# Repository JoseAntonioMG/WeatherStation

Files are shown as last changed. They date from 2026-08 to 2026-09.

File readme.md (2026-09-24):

# Project introduction

I created this project as a personal challenge to build a weather station, and also as a way to make use of an OpenThread mesh network using EspHome + HomeAssistant.

# Project function

1. Measure ambient temperature, humidity, and atmospheric pressure.

2. Measure the amount and intensity of rainfall.

3. Measure wind speed.

4. Measure wind direction.

# Hardware

I want to fabricate a PCB from the design I created in EasyEDA, which is shown in this program. The design includes the following elements:

1. An ESP32C6 microprocessor from espressif.
2. A lithium battery power system consisting of:
  - 3.7V single-cell lithium battery 18650
  - solar panel
  - Lithium battery protection and charging circuit with the components TP4056, DW0A1, and FS8205A
  - Voltage regulator with the TPS63802 circuit
3. A BME280 sensor for measuring temperature, humidity, and atmospheric pressure
4. A DS18B20 sensor for measuring external temperature via a probe
5. A battery monitor with readings on an ESP32C6 GPIO ADC and a voltage divider.
6. Hall effect sensors are used in the rain gauge and the anemometer. Each sensor connects to the ESP32C6 via the analog GPIO pins.
7. AS5600 is 12-bit magnetic position sensor for wind direction

# Software

The ESP32C6 uses Thread technology for data transmission, so I used the EspHome system in conjunction with the open-source HomeAssistant application and an OpenThread Border Router for communication with the internal network.

EspHome enables firmware updates over the Thread network itself, meaning that a device located in a hard-to-reach place can be updated automatically without physical access.

# Other manufacturing

I designed the different elements for measuring rain and wind on the OnShape platform:
- A rain gauge
- An anemometer
- An weathervane (wind direction)

I printed both elements with PETG filament on a 3D printer, and this is the result:

# Image gallery

## PCB:
This a PCB build from LCDPCB

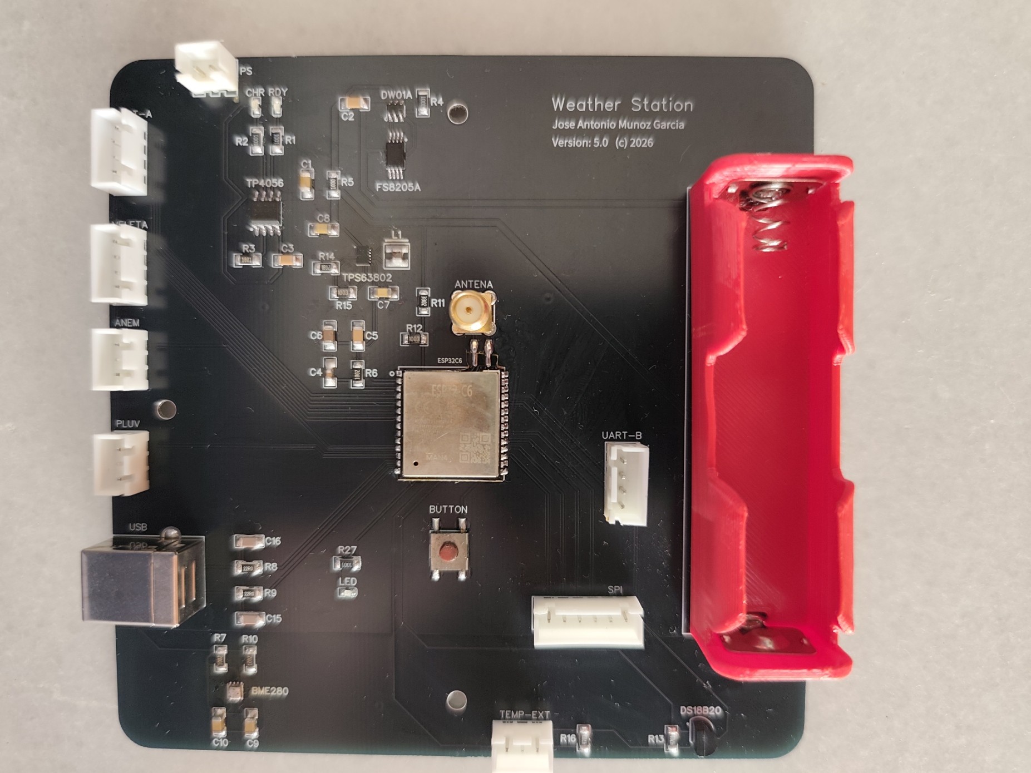
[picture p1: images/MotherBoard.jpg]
PCB


## Box outdoor and:
Airtight outdoor enclosure with grid for anchoring the PCB, battery and other electronic components.

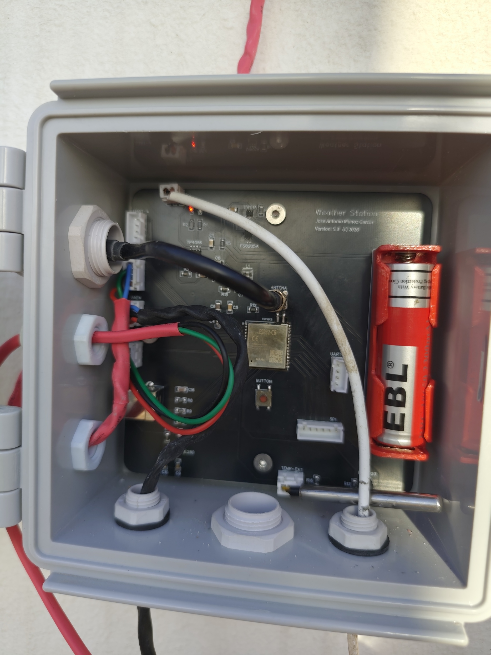
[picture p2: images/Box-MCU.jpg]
Outdoor Box


## BME280 Sensor:
The BME280 sensor from Bosch is a tiny device for soldering onto the PCB and records the internal temperature of the case where the MCU is located, as well as humidity and atmospheric pressure.

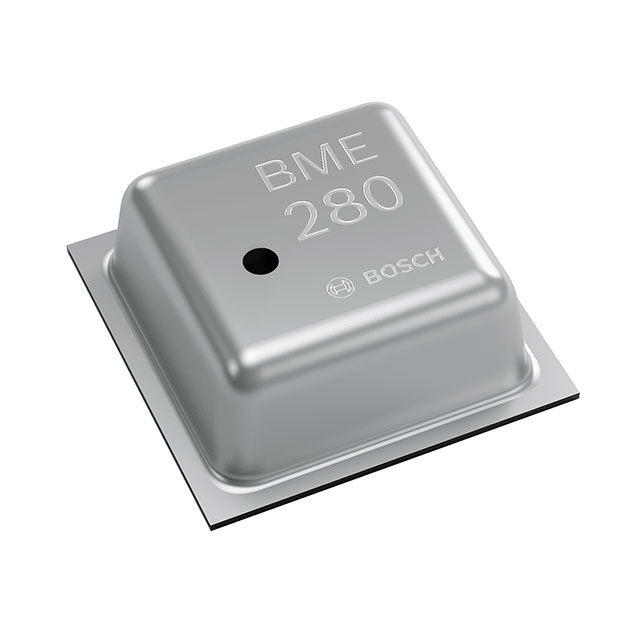
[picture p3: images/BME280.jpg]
BME280


## DS18B20 Sensor:
The DS18B20 is an outdoor temperature sensor; its metal sheath is protected against moisture and dust, and it can measure ambient temperature.

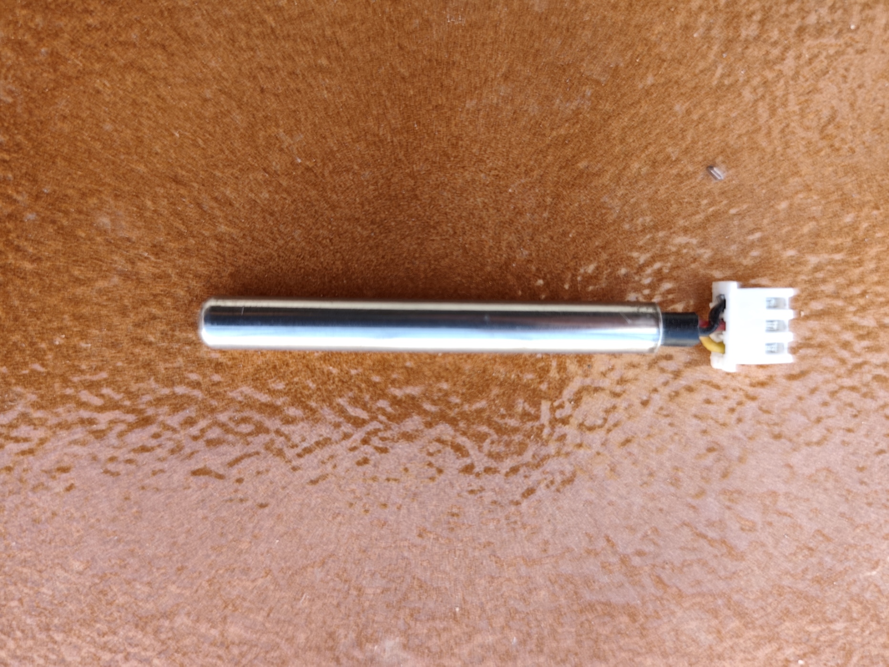
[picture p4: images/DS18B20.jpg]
DS18B20


## Rain Gauge:
Rain gauge seen from the outside, you can see the upper area (funnel) where there is a hole that allows water to enter and lead to the tipping bucket.

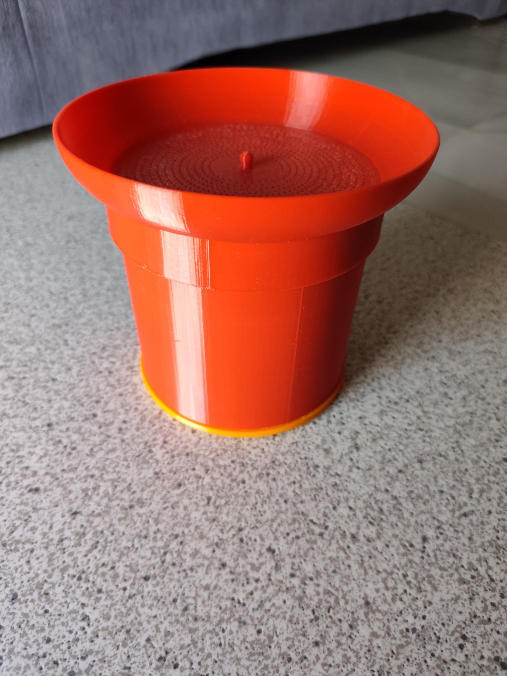
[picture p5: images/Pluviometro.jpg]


Interior rain gauge: the tipping bucket where the water falls can be seen, and in the front section, the Hall sensor that detects each revolution of the bucket. The neodymium magnet can be seen on the top of the tilting tank (a small metal piece). Using a mathematical formula, the amount of rainfall and intensity can be calculated for each revolution of the bucket, depending on the number of revolutions per minute.

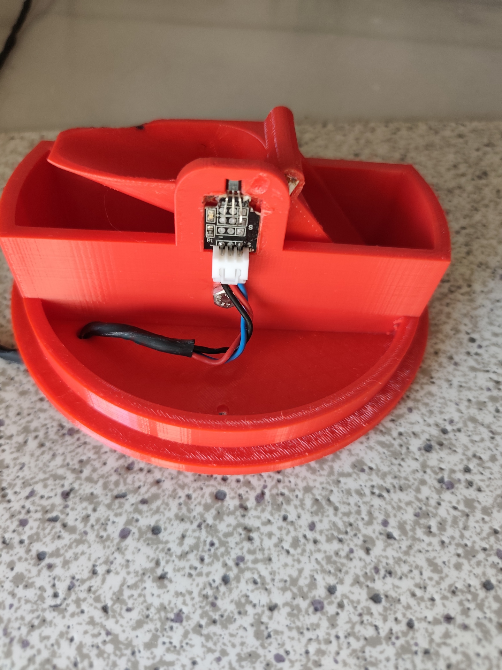
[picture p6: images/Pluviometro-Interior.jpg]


## Anemometer:
This device measures wind speed using a Hall effect sensor connected to its shaft and a neodymium magnet embedded in the rotating housing. Each pulse from the Hall sensor corresponds to one rotation of the device, and wind speed can be calculated using a mathematical formula.

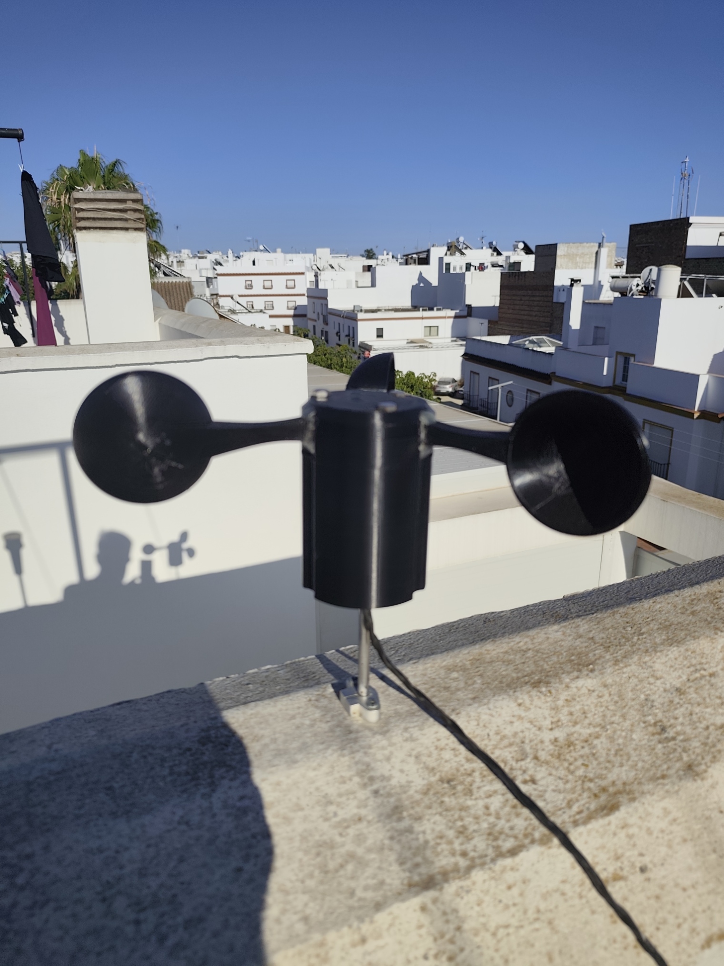
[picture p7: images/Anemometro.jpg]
Anenometer


## Weathervane:
Using an AS5600 sensor and a diametrically magnetized magnet. The AS5600 sensor remains fixed on a shaft; a dome containing the magnet at its base, approximately 2-3 mm from the sensor, rotates on this shaft. As the magnet rotates, the sensor can calculate its exact position in degrees and determine the wind direction.

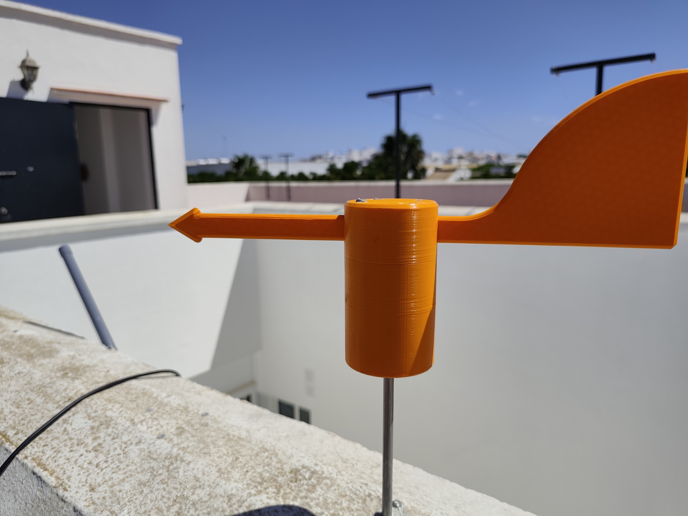
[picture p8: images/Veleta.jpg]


## Solar panel:
Allows the lithium battery to be recharged during daylight hours, and in this way the battery can power the MCU and sensors for many years.

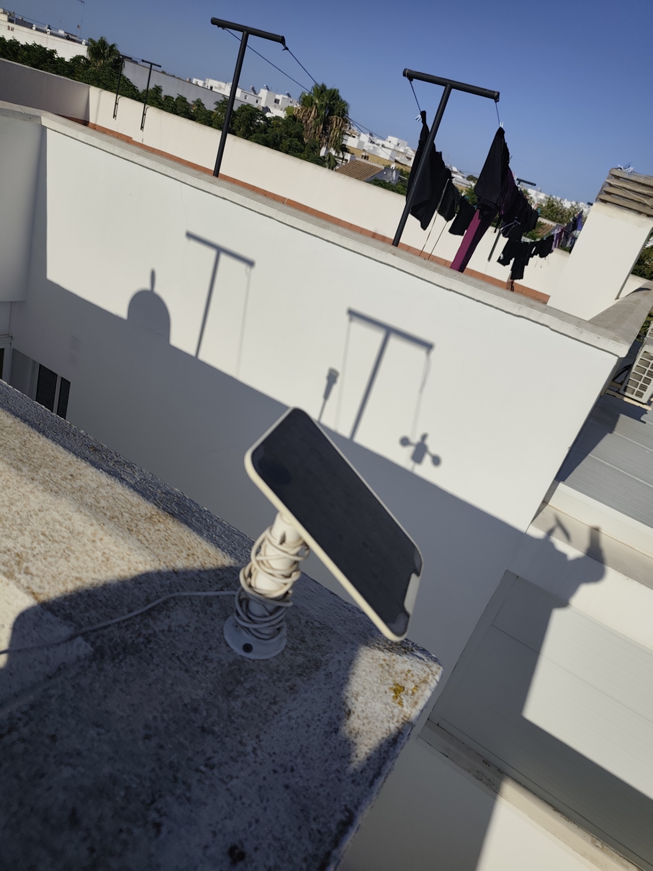
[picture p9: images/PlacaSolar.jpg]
Solar Panel


# OnShape Desing:

The rain gauge, anemometer and the weathervane were designed using the OnShape platform, and once designed they were printed on a 3D printer with PETG material.

General Rain Gauge Design:
https://cad.onshape.com/documents/2dcf995cedd97f664920bde0/w/8a44d4fc85dcee91b81b1610/e/77a74460ef746bb4184f5de4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

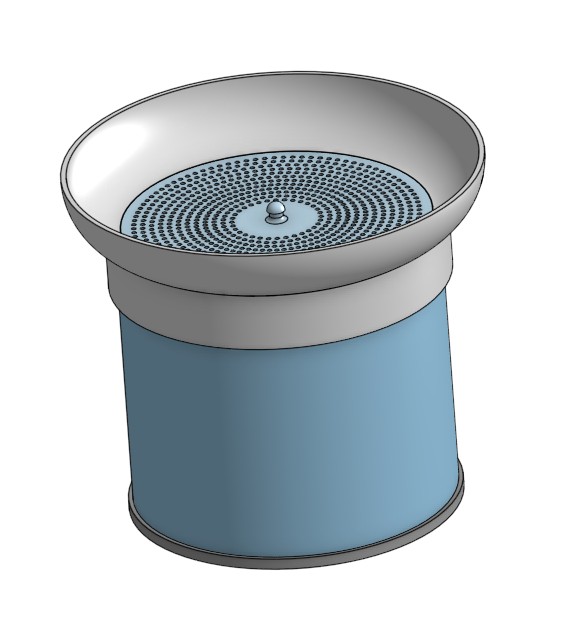
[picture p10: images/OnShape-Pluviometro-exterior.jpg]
Rain Gauge


Design of the interior rain gauge (tilting beam):

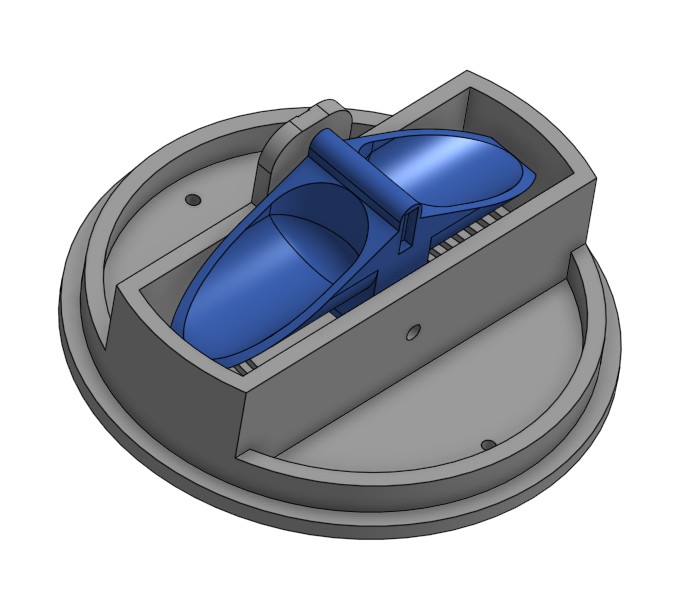
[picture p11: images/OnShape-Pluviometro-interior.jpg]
Rain Gauge interior


Rain gauge cross-section design:

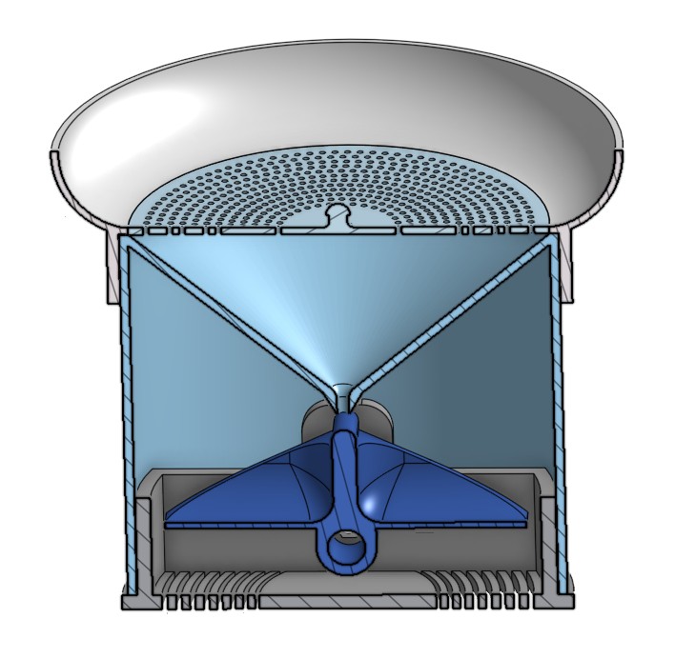
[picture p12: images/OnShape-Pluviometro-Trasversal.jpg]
Rain Gauge cross-section


Anemometer design overview:
https://cad.onshape.com/documents/6742c427159a326d2286ed9b/w/4320dd89b1448b79ad4a9c8e/e/1e7c80b05608dad78a0cc4f2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

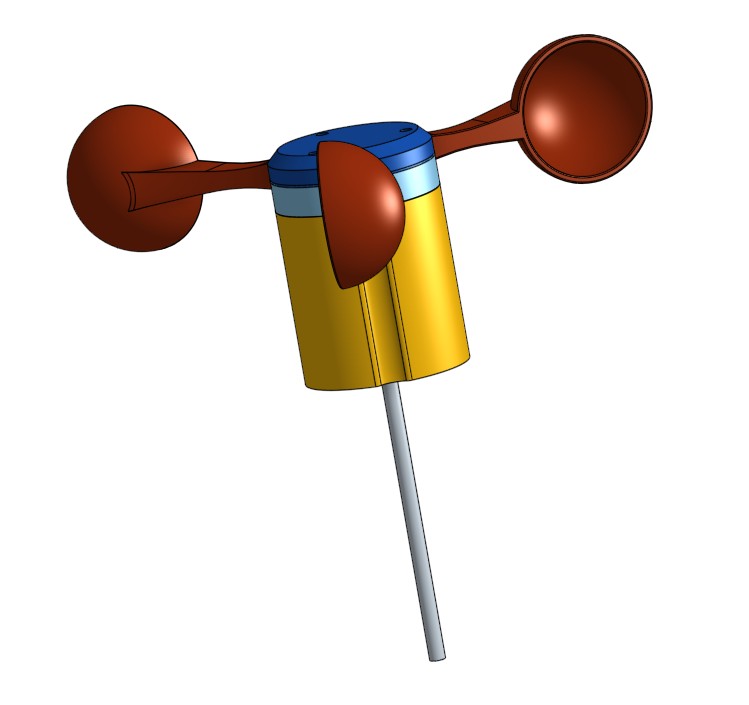
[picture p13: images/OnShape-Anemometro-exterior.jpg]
Anemometer


Cross-section design of the anemometer:

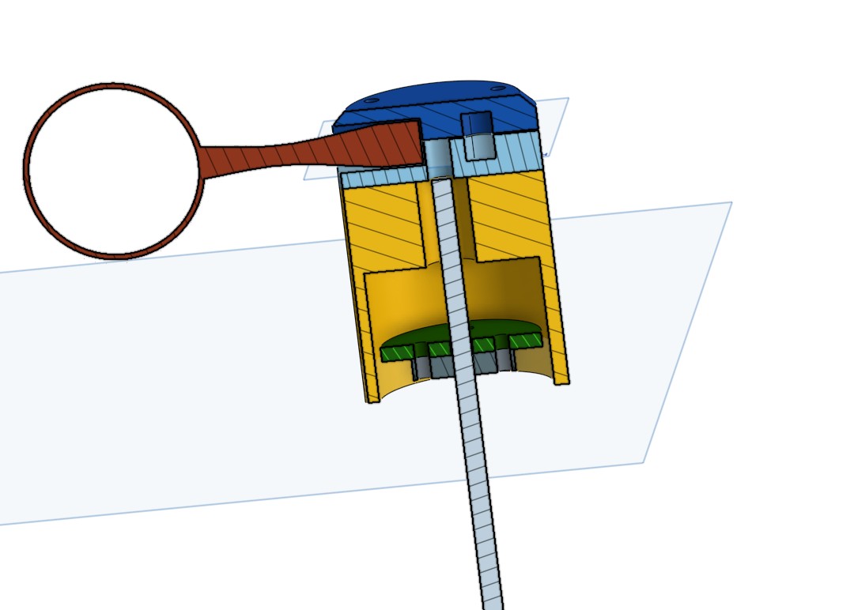
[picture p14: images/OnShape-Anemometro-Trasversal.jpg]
Anemometer cross-section


The 3144E is a magnetic hall effect sensor; when a magnet passes near the sensor, it emits an electrical pulse that is recorded in the MCU. Each pulse corresponds to one complete revolution of the anemometer, and therefore, the wind speed can be determined by calculating the number of revolutions the device has made in a given time.

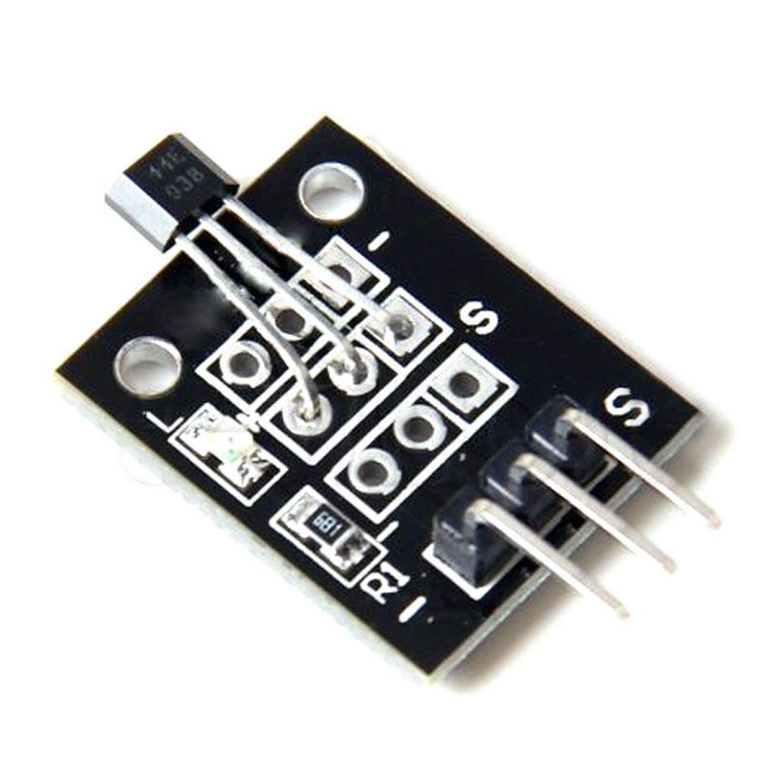
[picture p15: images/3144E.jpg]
3144E Sensor


Weathervane design:
https://cad.onshape.com/documents/b86387da9242ebc0d594fa96/w/6a7b8755a9ff353098229fa7/e/60776af953bbda5c55d1507b

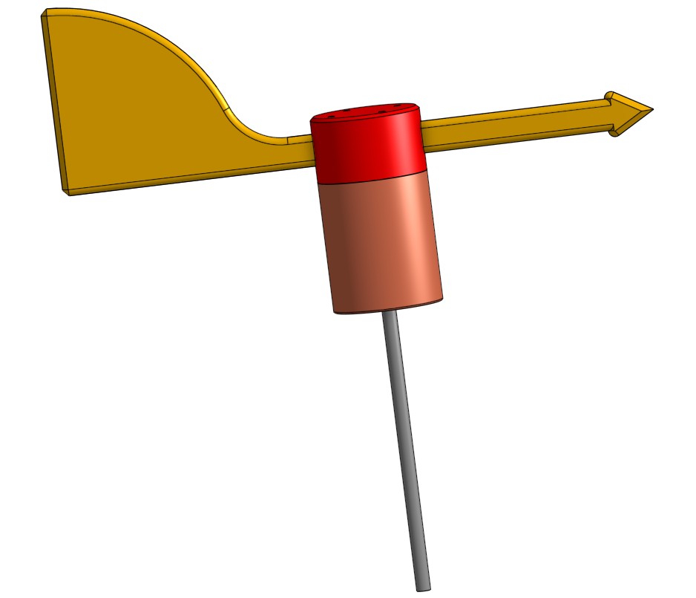
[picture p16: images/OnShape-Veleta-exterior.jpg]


Cross-section design of the weathervane:

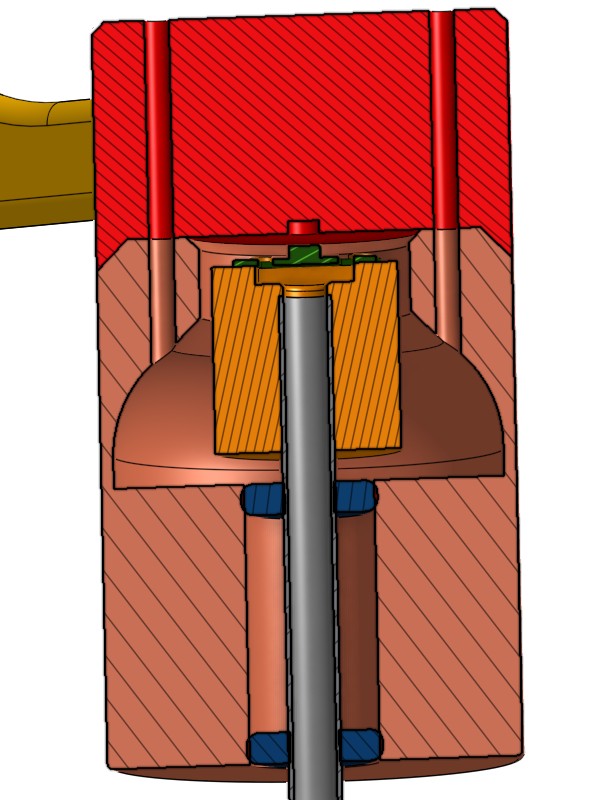
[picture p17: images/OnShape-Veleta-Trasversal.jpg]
Wathervane cross-section


The yellow part that holds the AS5600 board is visible, and the green part above it is the AS5600 sensor.
The dome (red) and the outer cylinder (brown) rotate around the axis (gray) via the bearings (blue).
The round magnet is located at the base of the dome (red), 2 mm from the sensor (green).

AS5600 sensor: for the weathervane is a magnetic position sensor.

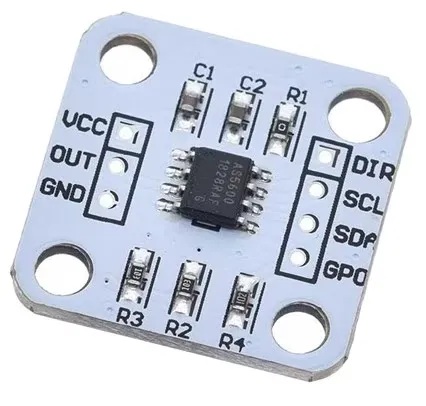
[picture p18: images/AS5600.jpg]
AS5600 sensor


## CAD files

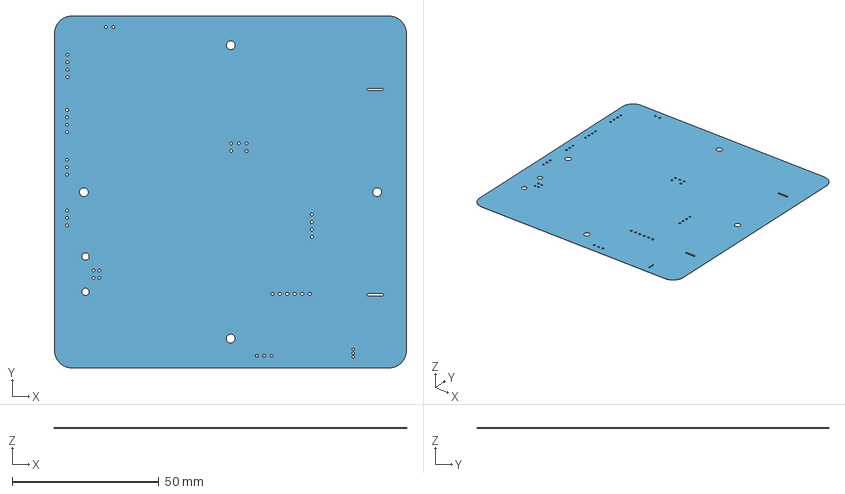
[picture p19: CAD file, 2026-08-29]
pcb/Weather-Station-3DO.step
120.0 x 120.0 x 0.09 mm
Board~fjnO
TopCopper~fjnO
BottomCopper~fjnO
TopSilkscreen~fjnO
BottomSilkscreen~fjnO
TopFpcStiffener~fjnO
BottomFpcStiffener~fjnO

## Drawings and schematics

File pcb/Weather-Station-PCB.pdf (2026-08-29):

No. | Quantity | Comment | Designator | Footprint | Value | Manufacturer Part | Manufacturer | Supplier Part | Supplier
1 | 3 | ZX-XH2.54-3 PZZ | ANEM,PLUV,TEMP-EXT | CONN-TH_3 P-P2.54_250 1S-3P | | ZX-XH2.54-3 PZZ | Megastar(兆 星) | C7429633 | LCSC
2 | 2 | TP/SP-3.0X1 .0 | ANT-NEG,ANT-POS | SOLDERPA D_3.0X1.0
3 | 1 | BWSMA-JW E | ANTENA | SMA-CONN ECTOR-PCB -CPY | | BWSMA-JW E | BAT WIRELE SS(蝙蝠无线) | C5250065 | LCSC
4 | 1 | BH-18650-A1 AJ006 | BATTERY | BAT-TH_BH-18650-A1AJ0 06 | | BH-18650-A1 AJ006 | MYOUNG(美 阳) | C5290175 | LCSC
5 | 1 | BME280 | BME280 | LGA-8_BME 280_BL | | BME280 | Bosch(博世) | C92489 | LCSC
6 | 1 | BUTTON | BUTTON | KEY-SMD_4 P-L6.0-W6.0-P4.50-LS9.0 | | BUTTON1 | null | C990001896 2 | LCSC
7 | 1 | 10uF | C1 | C1206 | | CL10A106M P8NNNC | SAMSUNG | C85713 | LCSC
8 | 2 | 100nF | C2,C3 | C1206 | | 0603B104K2 50 | WTC | C83054 | LCSC
9 | 1 | 1uF | C4 | C1206
10 | 1 | 100nF | C5 | C1206
11 | 4 | 22uF | C6,C7,C9,C10 | C1206
12 | 1 | 10uF | C8 | C1206
13 | 2 | 20pF | C15,C16 | C1206
14 | 1 | RED | CHR | LED0603_G REEN | | LTST-C191K RKT | LITEON | C125099 | LCSC
15 | 1 | DS18B20-TD | DS18B20 | TO-92-3_L4. 8-W3.7-P1.2 7-L | | DS18B20-TD | TDSEMIC(拓 电半导体) | C42421873 | LCSC
16 | 1 | DW01A | DW01A | SOT-23-6L | | DW01A | PUOLOP | C351410 | LCSC
17 | 1 | ESP32-C6-W ROOM-1U-N 8 | ESP32C6 | WIFIM-SMD_ 28P-L19.2-W 18.0-P1.27-T L | | ESP32-C6-W ROOM-1U-N 8 | null | C18212191 | LCSC
18 | 1 | FS8205A | FS8205A | TSSOP-8_L4 .4-W3.0-P0.6 5-LS6.4-BL-2 | | FS8205A | FORTUNE( 富晶) | C16052 | LCSC
19 | 1 | 470nH | L1 | IND-SMD_L4 .0-W4.0_XFL 4020-102ME B | | XFL4015-471 MEC | Coilcraft(线艺 ) | C18221164 | LCSC
20 | 1 | LED | LED | LED0603_G REEN | | 19-217/GHC-YR1S2/3T | EVERLIGHT( 台湾亿光) | C72043 | LCSC
21 | 1 | PlacasSolare s | PS | CONECT JST-XH-02 | | JST-XH-2P-M | JST | JST-XH-2P-M

22 | 3 | 1K | R1,R2,R4 | R1206 | ERJ3GEYJ1 02V | PANASONIC | C180848 | LCSC
23 | 1 | 1.8K | R3 | R1206 | RC0603JR-0 71K2L | YAGEO | C114679 | LCSC
24 | 1 | 100 | R5 | R1206 | 0603WAJ010 1T5E | UniOhm | C25201 | LCSC
25 | 3 | 10k | R6,R7,R10 | R1206
26 | 2 | 22 | R8,R9 | R1206
27 | 1 | 33k | R11 | R1206
28 | 1 | 100k | R12 | R1206
29 | 2 | 4.7k | R13,R16 | R1206 | RMC12064.7 K5%N | Tyohm(幸亚 电阻 ) | C269760 | LCSC
30 | 1 | 91k | R14 | R1206
31 | 1 | 510k | R15 | R1206
32 | 1 | 1k | R27 | R1206
33 | 1 | GREEN | RDY | LED0603_G REEN | LTST-C193T GKT-5A | LITEON | C12065 | LCSC
34 | 1 | SPI | SPI | CONN-TH_6 P-P2.50_XH 2.54-LI-6P | W-2501S06P -K000 | Ckmtw(灿科 盟) | C125204 | LCSC
35 | 1 | TP4056 | TP4056 | SOP-8_EP_1 50MIL | TP4056 | TOPPOWER | C16581 | LCSC
36 | 1 | TPS63802DL AT | TPS63802 | VSON-10-HR _L3.0-W2.0-P0.50-BL_TI _DLA | TPS63802DL AT | TI(德州仪器 ) | C1849531 | LCSC
37 | 3 | CONN-XH2.5 4-4P | UART-A,UART-B,VELETA | CONN-TH_4 P-P2.54_250 1S-4P | WAFER-XH2 .54-4PWZ | XUNPU(讯普 ) | C5359641 | LCSC
38 | 1 | USB-B10-BR W | USB | USB-B-TH_U SB-B10-BR W | USB-B10-BR W | XUNPU | C720549 | LCSC

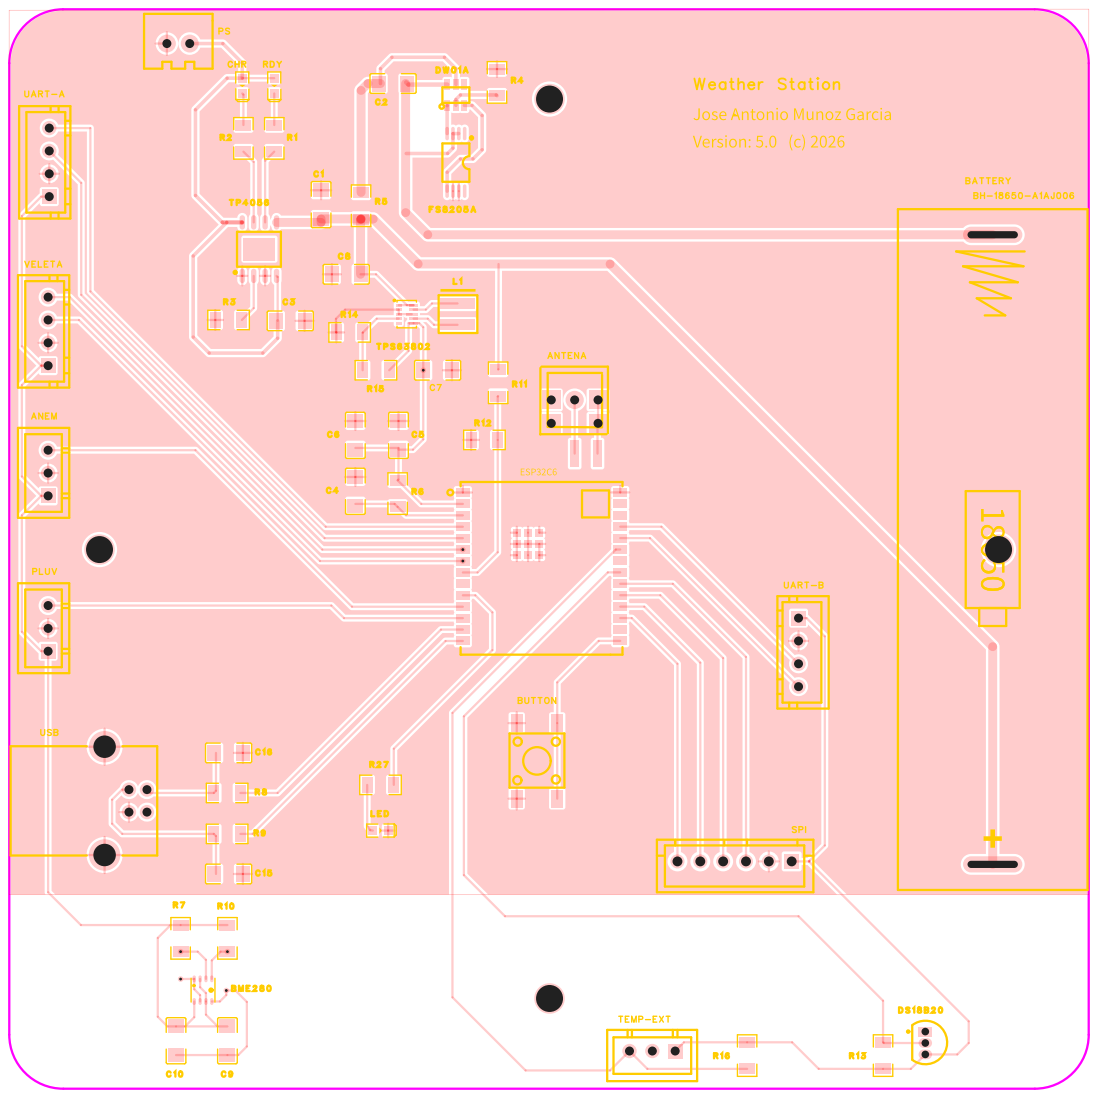
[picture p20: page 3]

Weather Station
Jose Antonio Munoz Garcia
Version: 5.0 (c) 2026

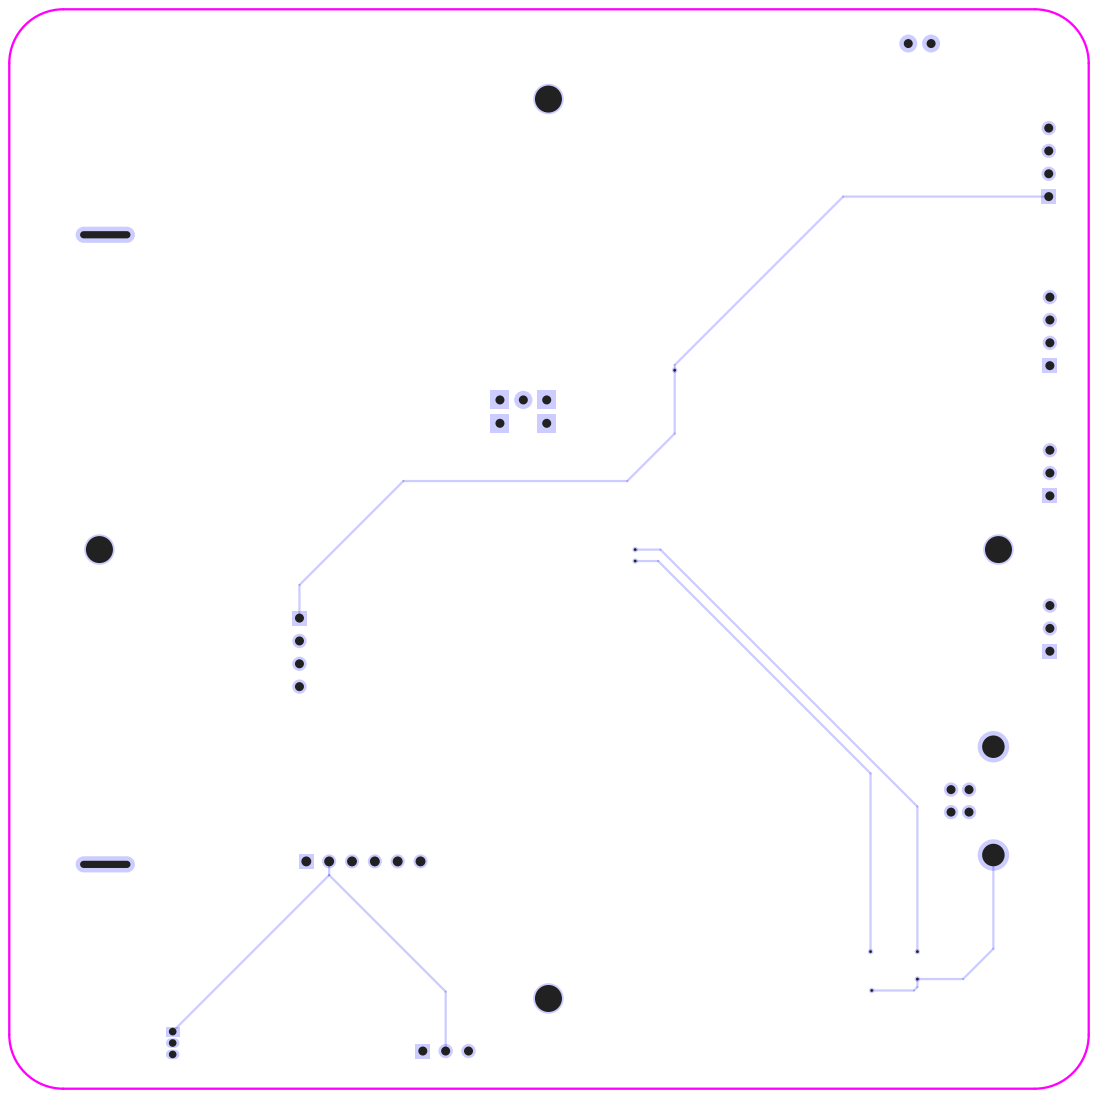
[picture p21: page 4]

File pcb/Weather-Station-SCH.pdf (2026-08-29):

BME280 | CONECTORES
MONITOR BATERIA | LEDs | REGULADOR VOLTAJE CPU

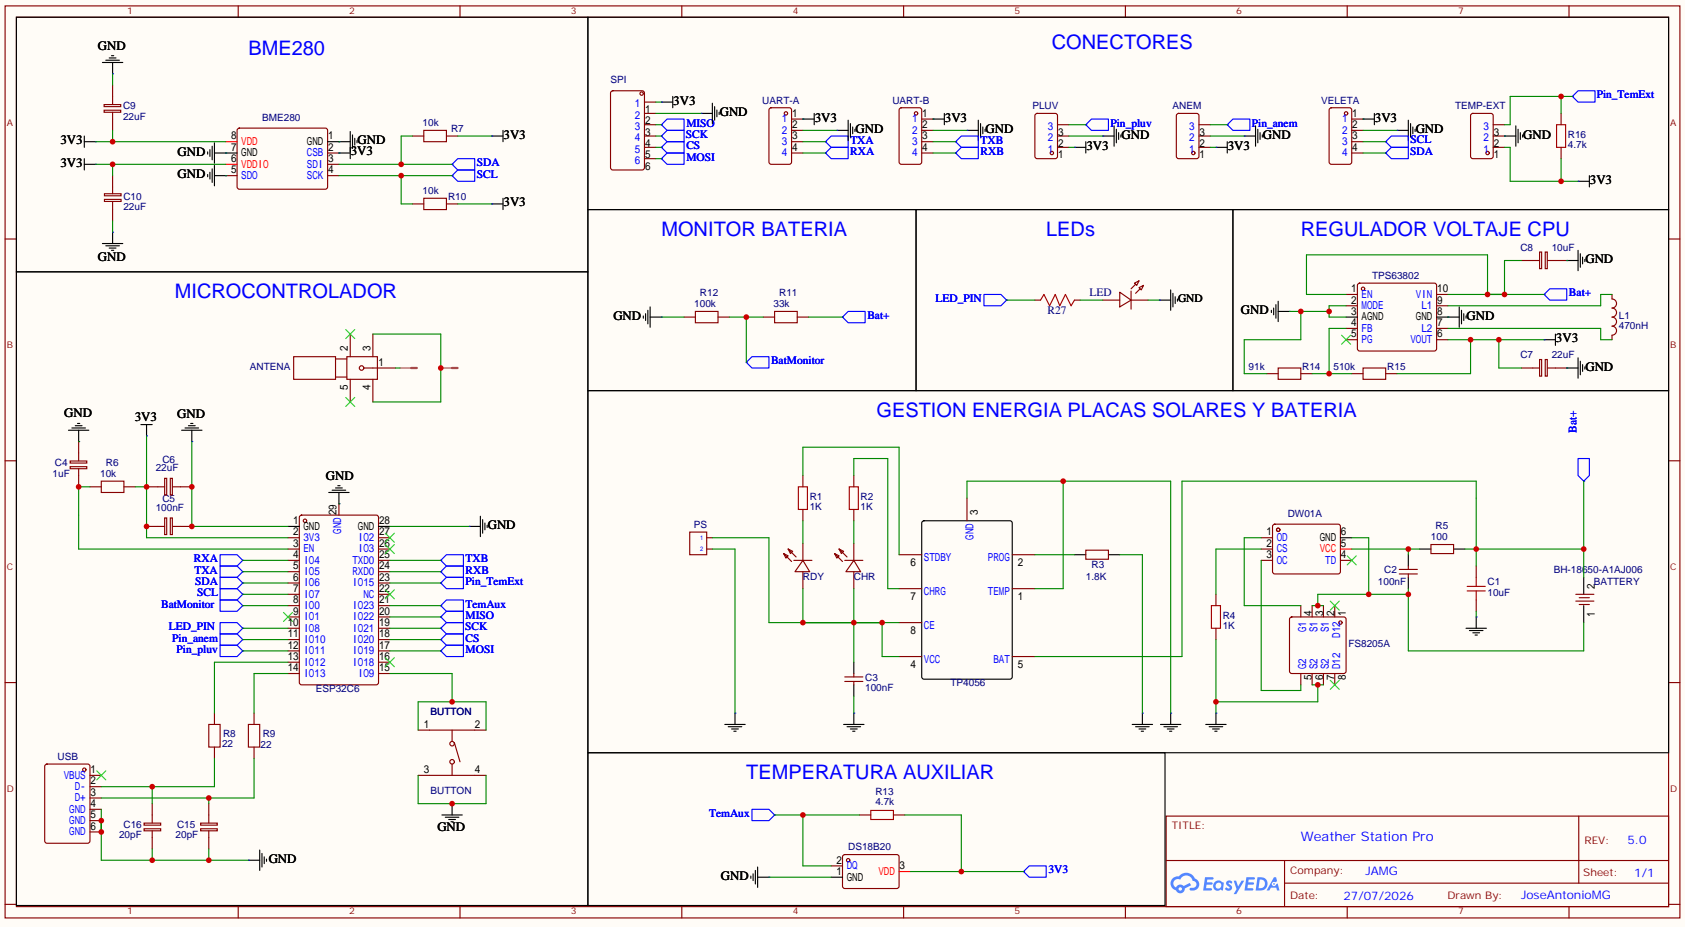
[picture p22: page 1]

GESTION ENERGIA PLACAS SOLARES Y BATERIA
